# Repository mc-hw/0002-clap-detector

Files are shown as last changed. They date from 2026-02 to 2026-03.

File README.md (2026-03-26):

# Clap detector (0002)

Clap-detecting switch

## Description

This circuit is a copy of [AVT-721/2](./AVT721_2.pdf) converted to Surface Mounted Technology.

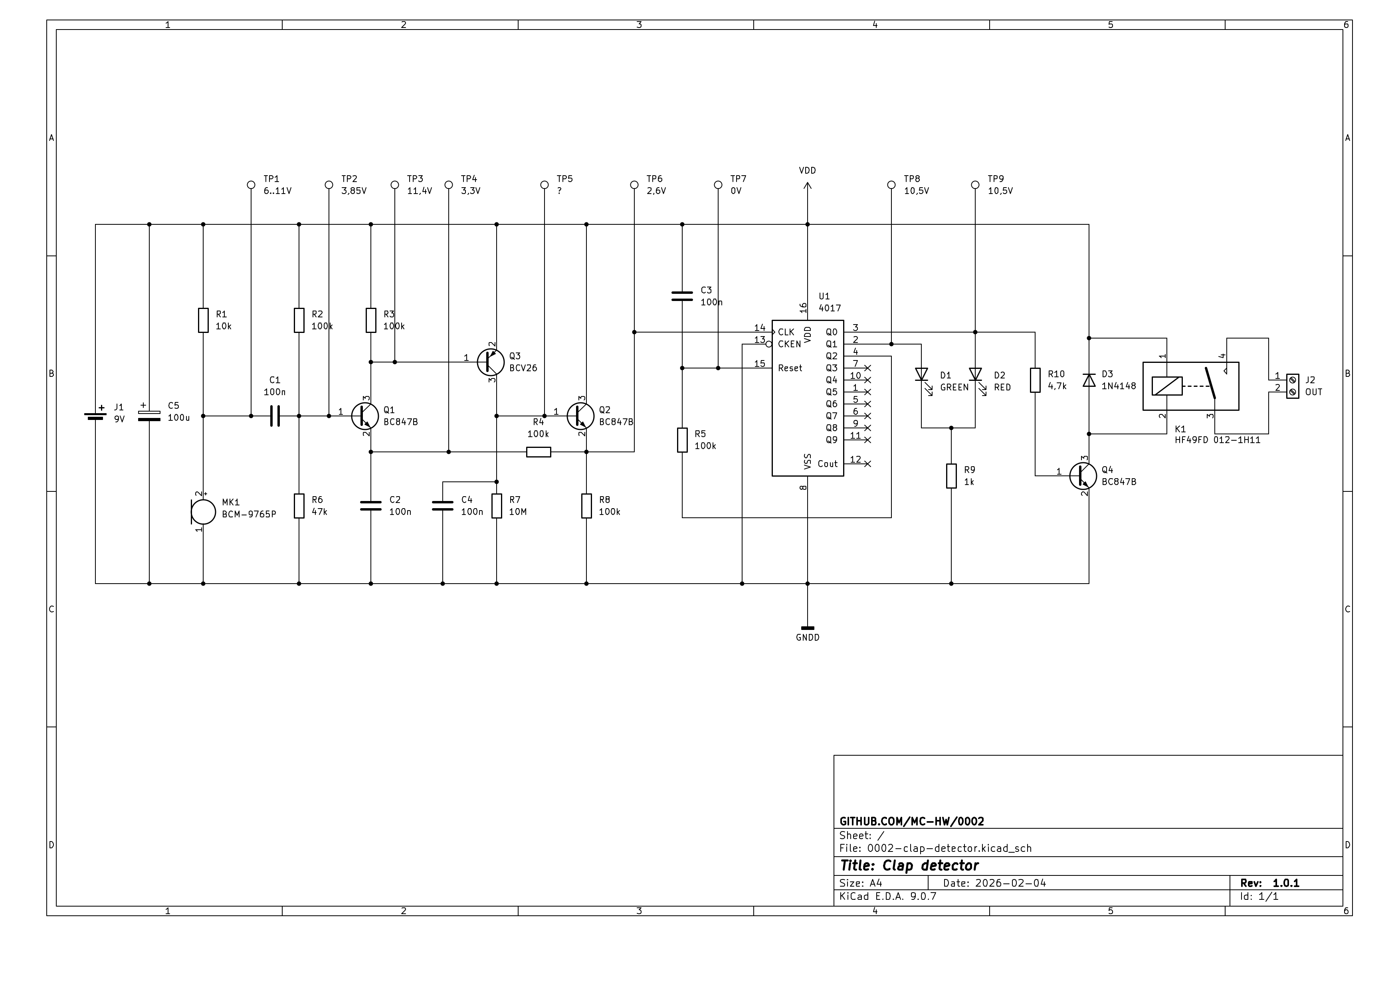
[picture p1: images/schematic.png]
Schematic


## Assembly

The circuit should be assembled on a double-sided, SMT printed circuit board.

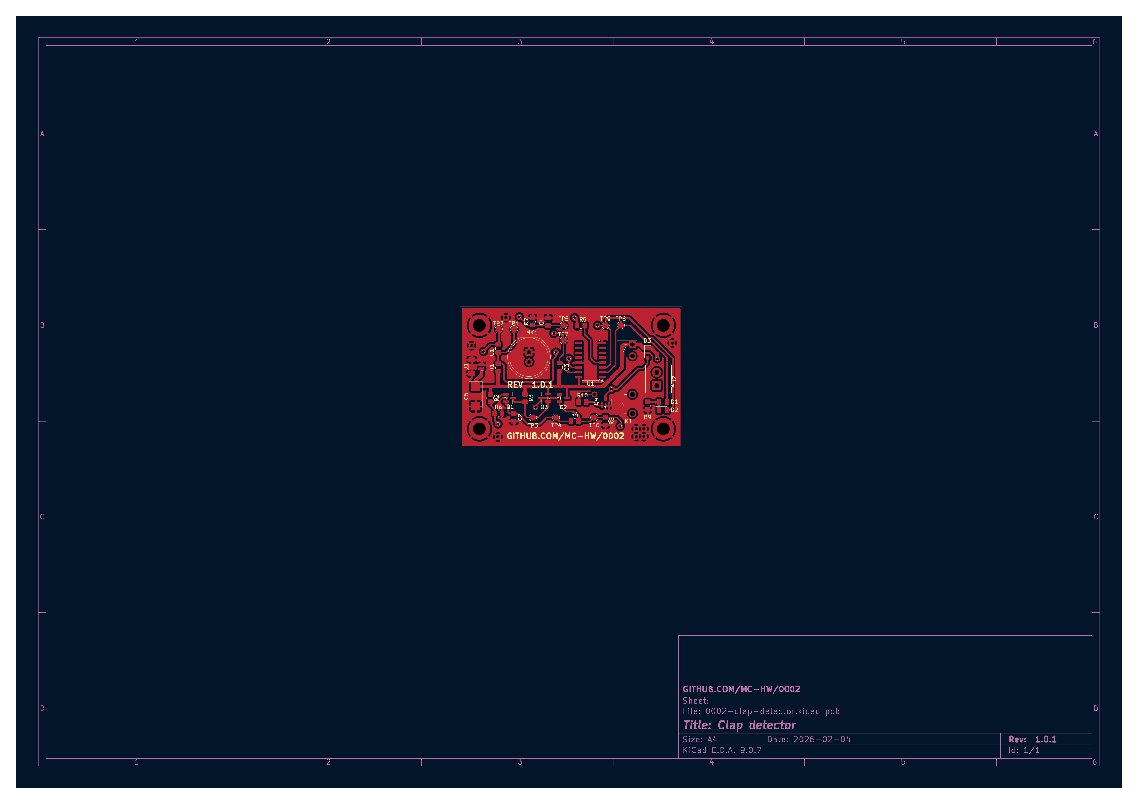
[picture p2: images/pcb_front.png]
PCB front layout


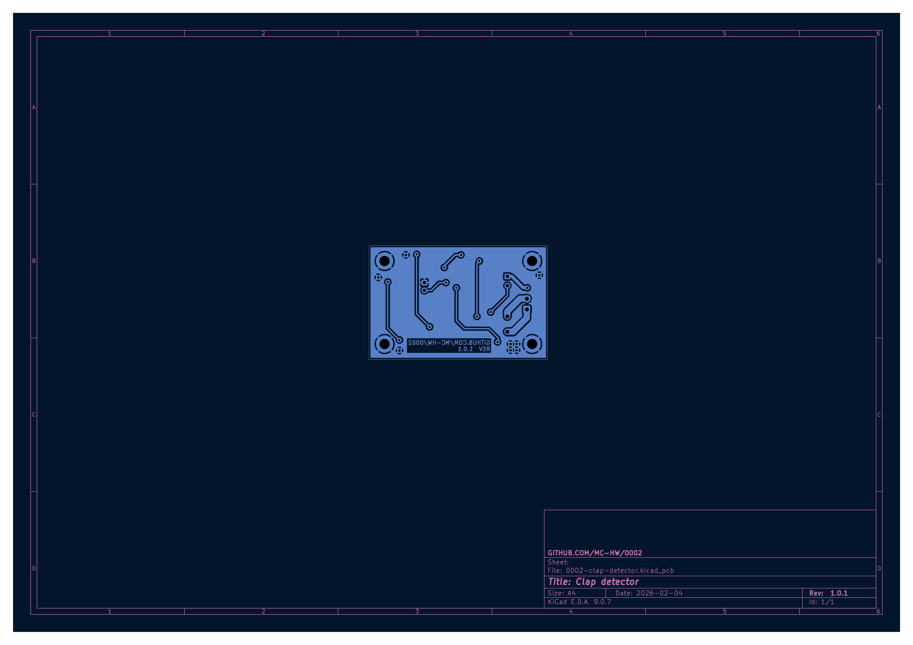
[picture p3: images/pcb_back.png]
PCB back layout


## Running

The device should be powered with 6-10DCV. It was intended to be powered from 6F22 9V battery connected to J1 connector.
The circuit after detecting a clap, switches D1 diode on and off. Additionally, it enables/disables K1 relay. A device
of max 230V/1000W can be enabled/disabled using J2 connector.

## Bill of materials

| Reference | Qty | Value | Package |
|---|-----|---|---|
| C1,C2,C3,C4 | 4 | 100n | 0805 |
| C5 | 1 | 100u | 2312 |
| D1 | 1 | GREEN | 0805 |
| D2 | 1 | RED | 0805 |
| D3 | 1 | 1N4148 | SOD-323 |
| J1 | 1 | 9V | JST-SH 1x2 PIN |
| J2 | 1 | OUT | ARK 3,5mm 1x2 PIN |
| K1 | 1 | HF49FD 012-1H11 | |
| MK1 | 1 | BCM-9765P | |
| Q1,Q2,Q4 | 3 | BC847B | SOT-23 |
| Q3 | 1 | BCV26 | SOT-23 |
| R1 | 1 | 10k | 0805 |
| R2,R3,R4,R5,R8 | 5 | 100k | 0805 |
| R6 | 1 | 47k | 0805 |
| R7 | 1 | 10M | 0805 |
| R9 | 1 | 1k | 0805 |
| R10 | 1 | 4,7k | 0805 |
| U1 | 1 | 4017 | SOP-16 |

## Implementation

# Solder mask

The amount of solder mask should not be to thin, distributing with plastic card should not be necessary,
pressure with plexi glass should be enough to distribute it.
The stencil was printed ink-down, twice. Light exposure was performed through a stencil only, no glass on top.
Each corner was exposed for 40 minutes, long edges for 20 minutes, two central points for 15 minutes each.

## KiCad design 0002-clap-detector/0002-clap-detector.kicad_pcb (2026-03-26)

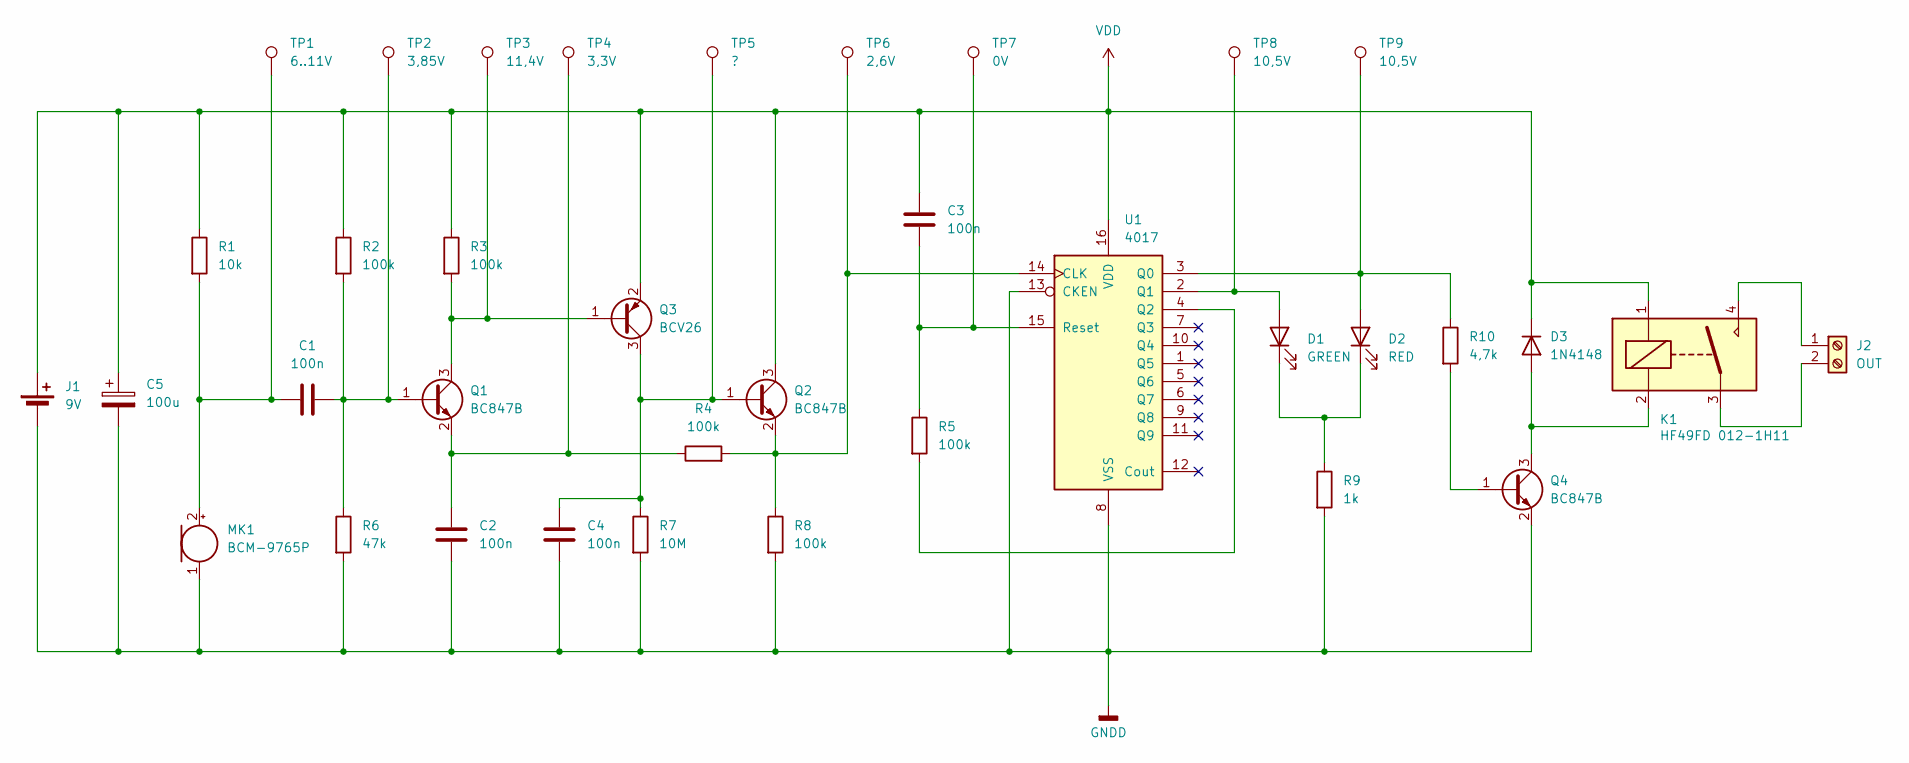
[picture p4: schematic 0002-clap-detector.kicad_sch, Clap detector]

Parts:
C1, C2, C3, C4: 100n; C_0805_2012Metric_Pad1.18x1.45mm_HandSolder
C5: 100u; CP_EIA-6032-28_Kemet-C_HandSolder
D1: GREEN; LED_0805_2012Metric_Pad1.15x1.40mm_HandSolder
D2: RED; LED_0805_2012Metric_Pad1.15x1.40mm_HandSolder
D3: 1N4148; D_SOD-323_HandSoldering
J1: 9V; JST_SH_BM02B-SRSS-TB_1x02-1MP_P1.00mm_Vertical
J2: OUT; TerminalBlock_MetzConnect_Type059_RT06302HBWC_1x02_P3.50mm_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
K1: HF49FD 012-1H11; Relay_SPST_TE_PCN-1xxD3MHZ
MK1: BCM-9765P; LED_D10.0mm
Q1, Q2, Q4: BC847B; SOT-23
Q3: BCV26; SOT-23
R1: 10k; R_0805_2012Metric_Pad1.20x1.40mm_HandSolder
R2, R3, R4, R5, R8: 100k; R_0805_2012Metric_Pad1.20x1.40mm_HandSolder
R6: 47k; R_0805_2012Metric_Pad1.20x1.40mm_HandSolder
R7: 10M; R_0805_2012Metric_Pad1.20x1.40mm_HandSolder
R9: 1k; R_0805_2012Metric_Pad1.20x1.40mm_HandSolder
R10: 4,7k; R_0805_2012Metric_Pad1.20x1.40mm_HandSolder
TP1: 6..11V; TestPoint_Pad_D1.5mm
TP2: 3,85V; TestPoint_Pad_D1.5mm
TP3: 11,4V; TestPoint_Pad_D1.5mm
TP4: 3,3V; TestPoint_Pad_D1.5mm
TP5: ?; TestPoint_Pad_D1.5mm
TP6: 2,6V; TestPoint_Pad_D1.5mm
TP7: 0V; TestPoint_Pad_D1.5mm
TP8, TP9: 10,5V; TestPoint_Pad_D1.5mm
U1: 4017; SOP-16_4.4x10.4mm_P1.27mm

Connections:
GNDD: C2.2, C4.2, C5.2, J1.2 (-), J1.MP, MK1.1 (-), Q4.2 (E), R6.2, R7.2, R8.2, R9.2, U1.8 (VSS), U1.13 (CKEN)
unnamed: D1.2 (A), TP8.1, U1.2 (Q1)
unnamed: D1.1 (K), D2.1 (K), R9.1
unnamed: D2.2 (A), R10.1, TP9.1, U1.3 (Q0)
unnamed: D3.2 (A), K1.2, Q4.3 (C)
unnamed: J2.1, K1.4
unnamed: J2.2, K1.3
unnamed: C1.2, MK1.2 (+), R1.2, TP1.1
unnamed: C1.1, Q1.1 (B), R2.2, R6.1, TP2.1
unnamed: Q1.3 (C), Q3.1 (B), R3.2, TP3.1
unnamed: C2.1, Q1.2 (E), R4.1, TP4.1
unnamed: C4.1, Q2.1 (B), Q3.3 (C), R7.1, TP5.1
unnamed: Q2.2 (E), R4.2, R8.1, TP6.1, U1.14 (CLK)
unnamed: Q4.1 (B), R10.2
unnamed: R5.2, U1.4 (Q2)
unnamed: C3.2, R5.1, TP7.1, U1.15 (Reset)
VDD: C3.1, C5.1, D3.1 (K), J1.1 (+), K1.1, Q2.3 (C), Q3.2 (E), R1.1, R2.1, R3.1, U1.16 (VDD)

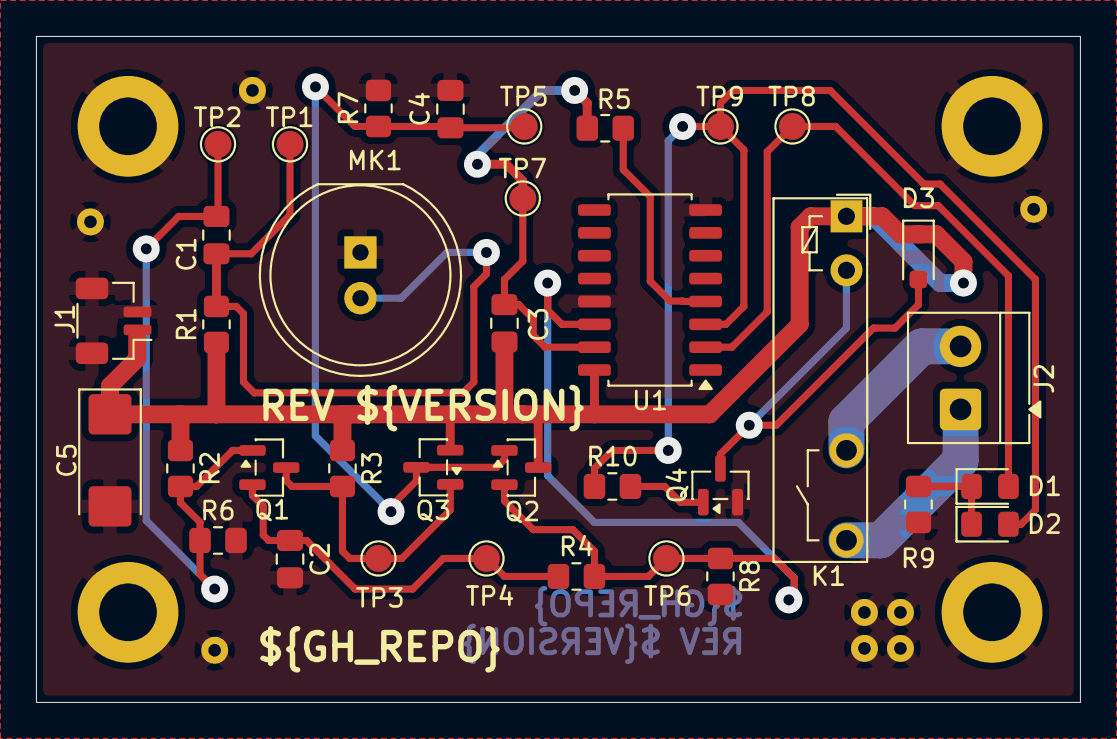
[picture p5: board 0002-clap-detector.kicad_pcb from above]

Board: 2 copper layers, 58.0 x 37.0 mm, 36 parts (0 on the bottom side), 17 nets.

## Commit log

2025-12-11 Circuit description (#1)
2025-12-18 Schematic (#2)
    * KiCAD files
    * Electric schematic
    * Schematics
    ---------
    [0002-clap-detector.kicad_pcb, 0002-clap-detector.kicad_sch]
2025-12-20 Assign footprints to components (#3)
    [0002-clap-detector.kicad_sch]
2025-12-30 Pcb layout (#4)
    * PCB layout
    * PCB layout refecences
    * Small corrections
    * PCB corrections
    * Disable mirror
    * Fix validation error
    * Cleanup
    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
    [0002-clap-detector.kicad_pcb]
2026-01-01 PCB - small correction (#5)
    [0002-clap-detector.kicad_pcb]
2026-01-13 Bill of materials (#6)
2026-02-05 Small corrections (#7)
    * Remove solder mask documentation
    * Solder mask hints
    * Update schematic and pcb
    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
    [0002-clap-detector.kicad_pcb]
2026-03-09 Remove solder mask from fat traces (#8)
    [0002-clap-detector.kicad_pcb]
2026-03-26 Solder mask hints (#9)
    * Alter solder mask hints
    * Correction
    * Migrate to KiCAD 10
    [0002-clap-detector.kicad_pcb, 0002-clap-detector.kicad_sch]
